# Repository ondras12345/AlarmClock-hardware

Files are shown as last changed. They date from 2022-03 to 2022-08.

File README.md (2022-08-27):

# AlarmClock Hardware
This repository contains hardware design files for [AlarmClock][AlarmClock].

Schematics and PCBs are designed in [KiCAD][KiCAD].

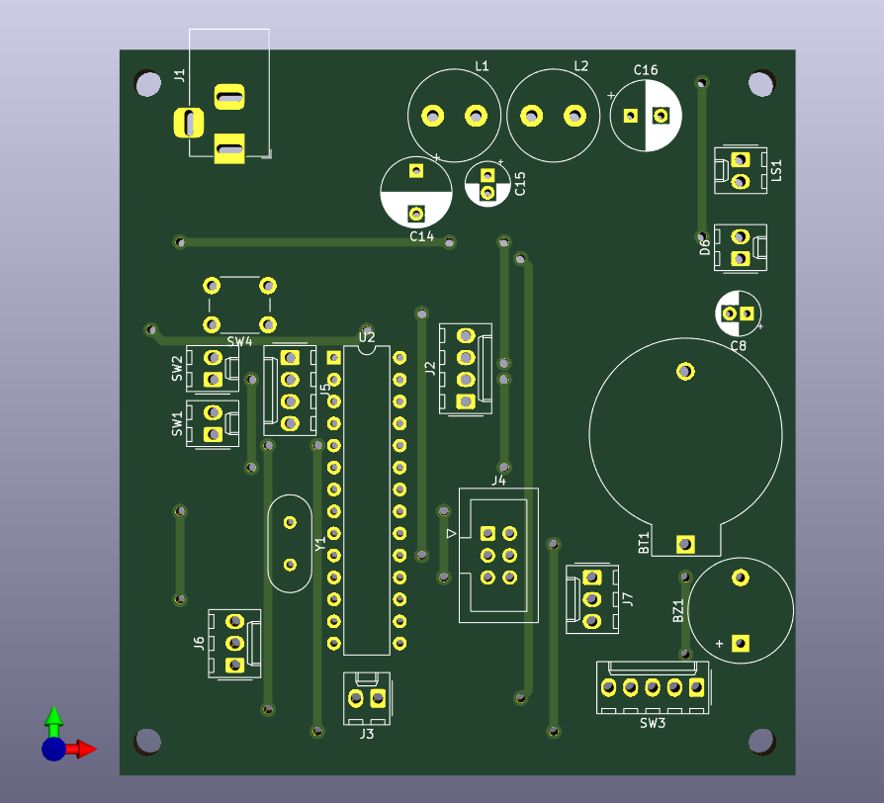
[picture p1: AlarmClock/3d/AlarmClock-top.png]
3D rendering of the top side of the PCB

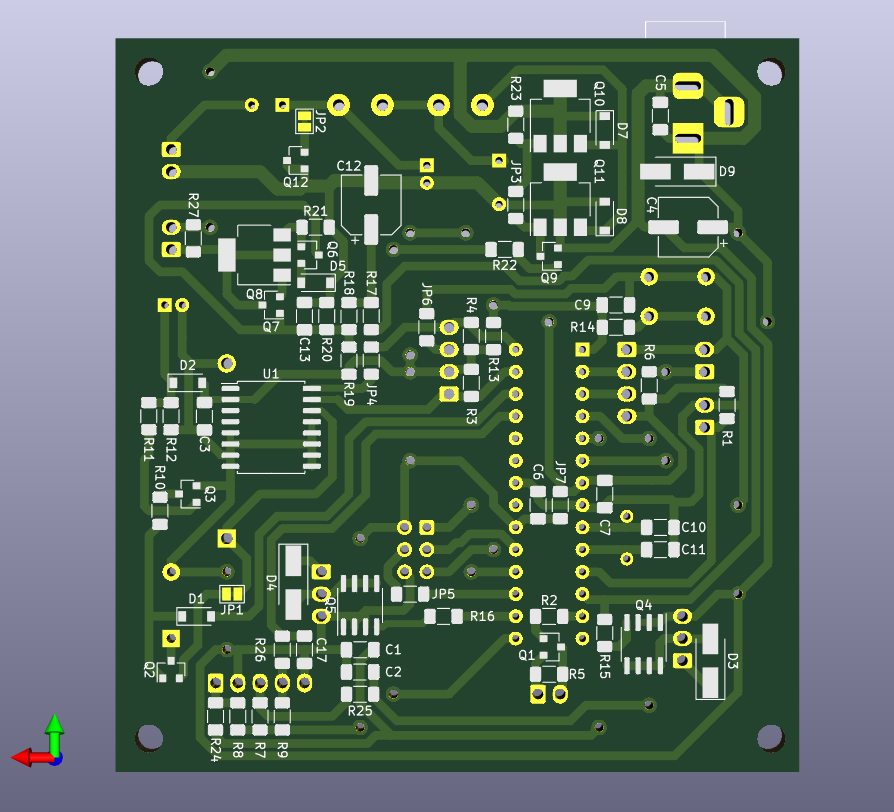
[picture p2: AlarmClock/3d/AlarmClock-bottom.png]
3D rendering of the bottom side of the PCB

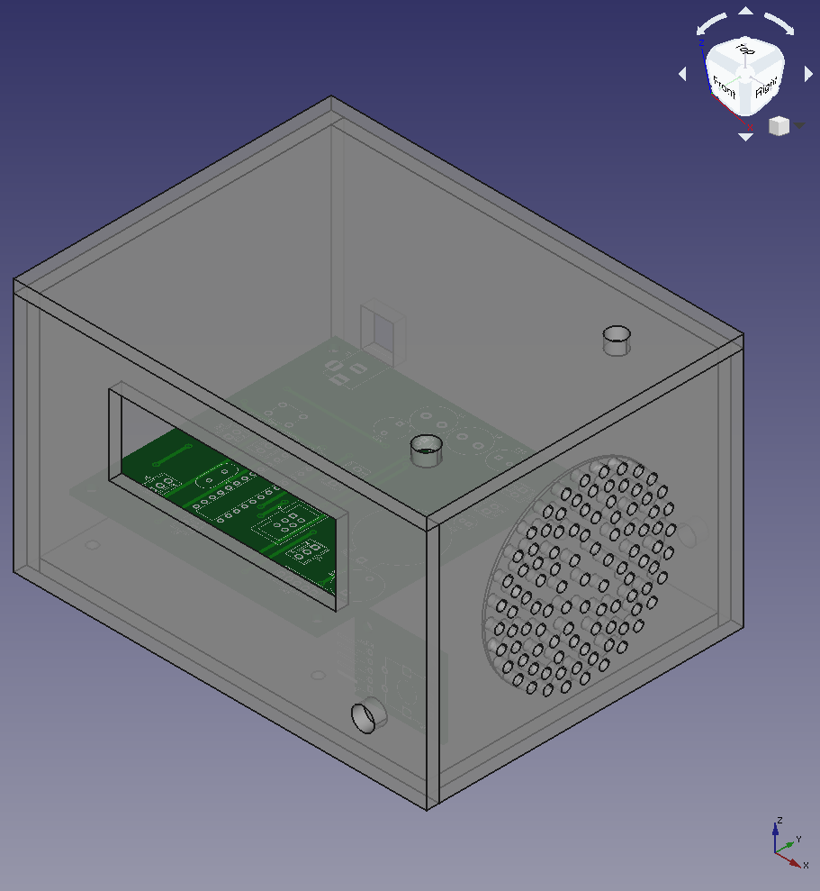
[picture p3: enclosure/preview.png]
3D view of the enclosure


[AlarmClock]: https://github.com/ondras12345/AlarmClock
[KiCAD]: https://www.kicad.org/

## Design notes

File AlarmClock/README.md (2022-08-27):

# AlarmClock
This is the main project for the whole thing. Both schematics and PCB design.

3D rendering of the top side of the PCB
3D rendering of the bottom side of the PCB

[Schematics](./AlarmClock.pdf)
[PCB](./AlarmClock-PCB.pdf)

The PCB is designed to be milled out from a single sided copper clad laminate
on a CNC machine. However, the design should also be suitable for standard
etching.

**Warning**: R27 is currently NOT included in the gcode files in `cnc/`.
However, it is quite easy to bodge in if you don't want to mess with `FlatCAM`
to fix this. Gerber files are OK.

## MCU pinout
Pin numbers in the firmware are using the convention set by the Arduino
framework. To map them to MCU pins, use the following table:

|Arduino pin | MCU pin |
|:---|:---|
| 0 | PD0 |
| 1 | PD1 |
| 2 | PD2 |
| 3 | PD3 |
| 4 | PD4 |
| 5 | PD5 |
| 6 | PD6 |
| 7 | PD7 |
| 8 | PB0 |
| 9 | PB1 |
| 10 | PB2 |
| 11 | PB3 |
| 12 | PB4 |
| 13 | PB5 |
| A0 | PC0 |
| A1 | PC1 |
| A2 | PC2 |
| A3 | PC3 |
| A4 | PC4 |
| A5 | PC5 |

- https://www.arduino.cc/en/uploads/Main/Arduino_Uno_Rev3-schematic.pdf

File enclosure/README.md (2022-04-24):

# Enclosure
This directory contains FreeCAD designs of the enclosure and gcode for
manufacturing some parts of it on a CNC mill.

The enclosure is made of 4 mm thick plywood. The sides are glued together.
The back side is removable.

3D view of the enclosure

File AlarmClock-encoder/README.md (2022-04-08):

# AlarmClock-encoder
This is just a small PCB for a Bourns PEC11R-4220K-S0024 rotary encoder.
It's only function is to connect the encoder, which is mounted to the front
panel, to a cable.

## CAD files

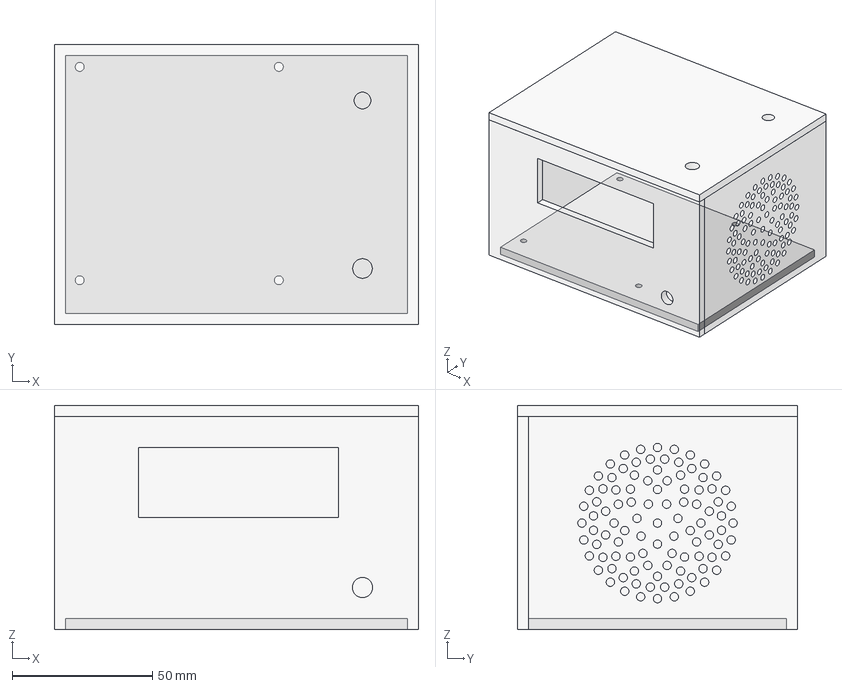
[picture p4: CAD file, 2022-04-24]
enclosure/enclosure.FCStd
130.0 x 100.0 x 80.0 mm
top
front
right
back
bottom
left

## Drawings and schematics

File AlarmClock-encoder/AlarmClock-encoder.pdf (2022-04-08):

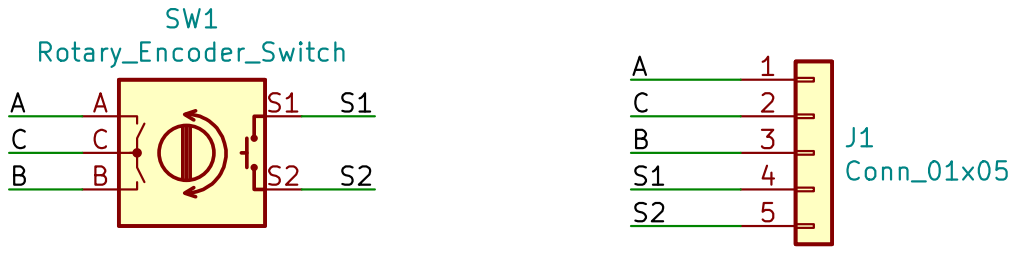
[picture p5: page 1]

Id: 1/1 Title: File: AlarmClock-encoder.sch Sheet: / Ondej Sluka

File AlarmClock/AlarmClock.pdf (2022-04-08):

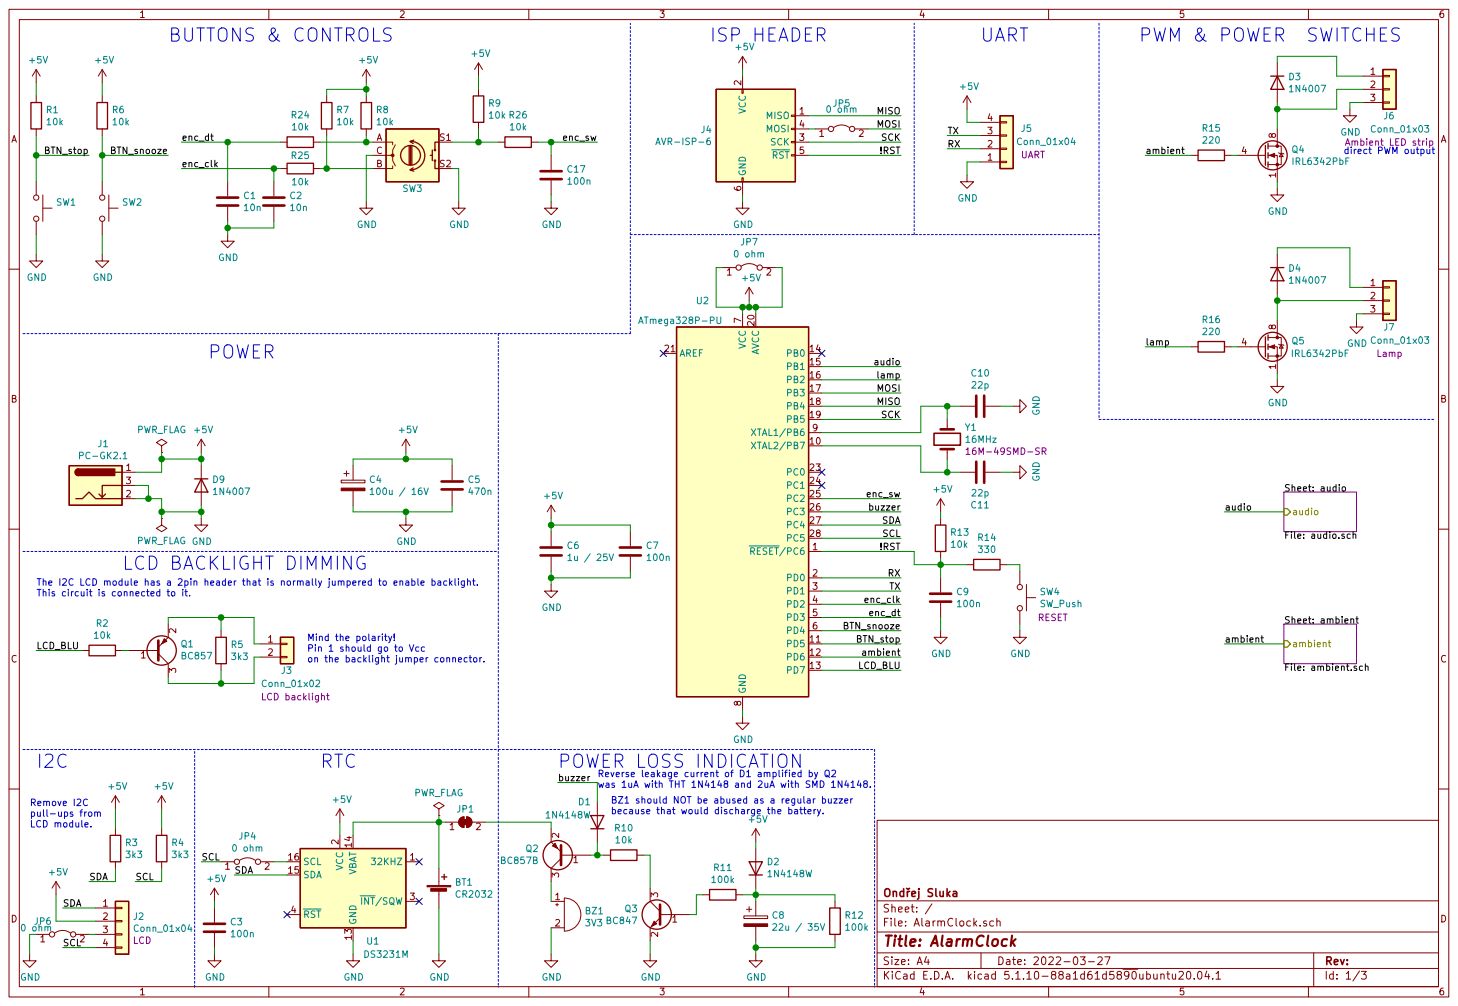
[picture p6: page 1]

2 SCK 3 MOSI 4 RST 5 GND

J6 Conn_01x03 Ambient LED strip GND

lamp
!RST SCK MOSI MISO

ambient Sheet: audio File: audio.sch

Reverse leakage current of D1 amplified by Q2 was 1uA with THT 1N4148 and 2uA with SMD 1N4148. Mind the polarity!
Pin 1 should go to Vcc
on the backlight jumper connector.

BZ1 should NOT be abused as a regular buzzer
because that would discharge the battery.

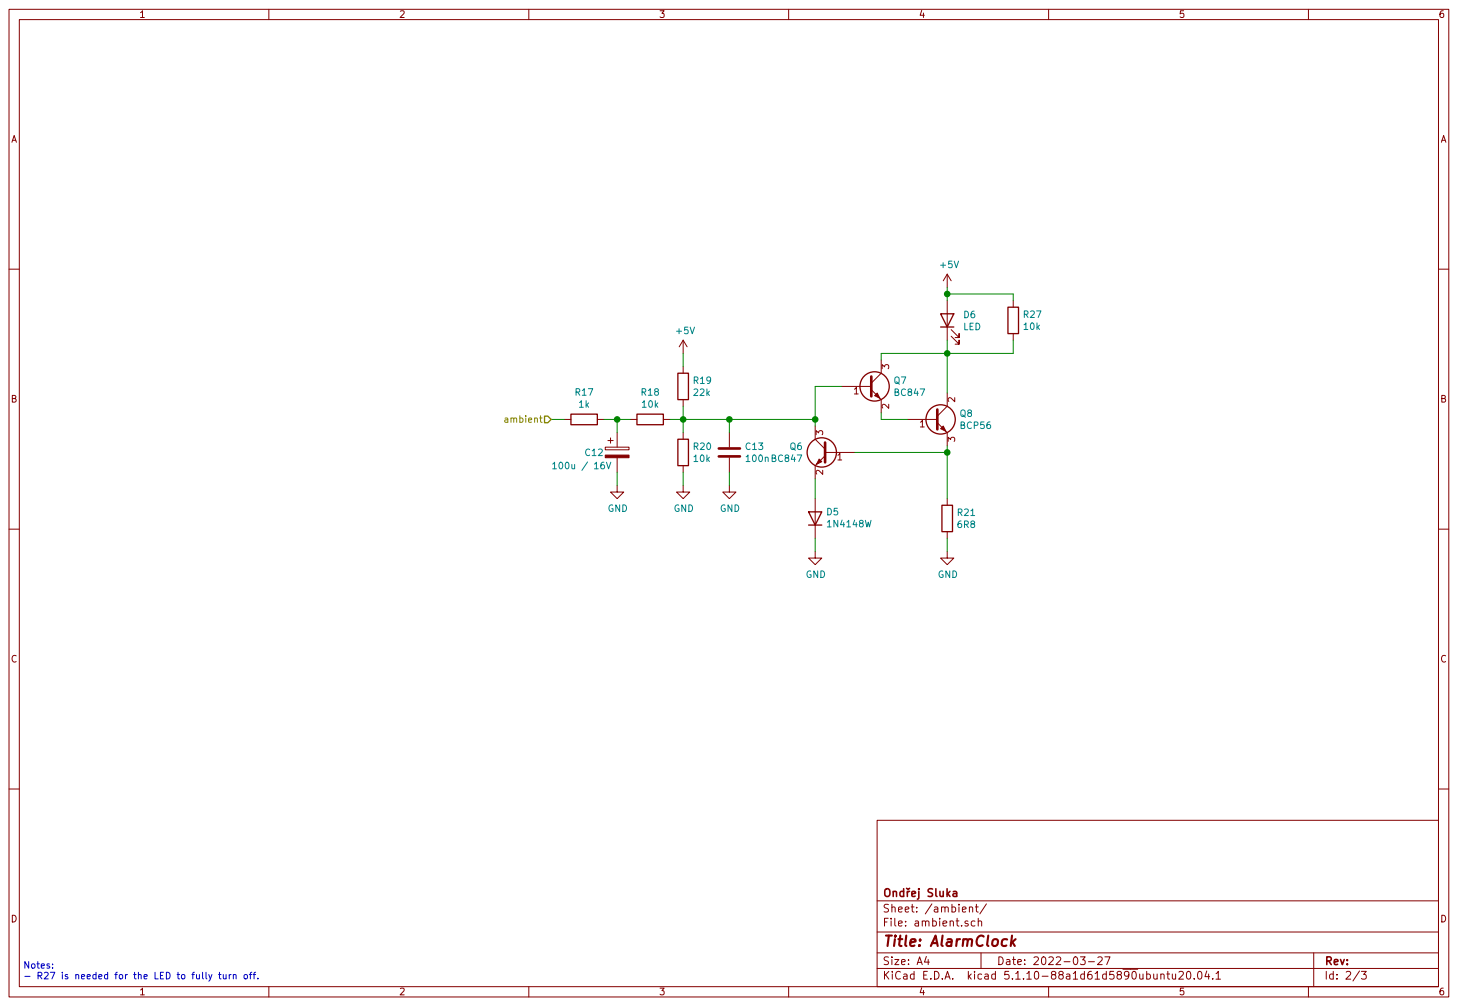
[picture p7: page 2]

2 3 Q8BCP56 ambient Notes: - R27 is needed for the LED to fully turn off.

File: ambient.sch Sheet: /ambient/ Ondej Sluka

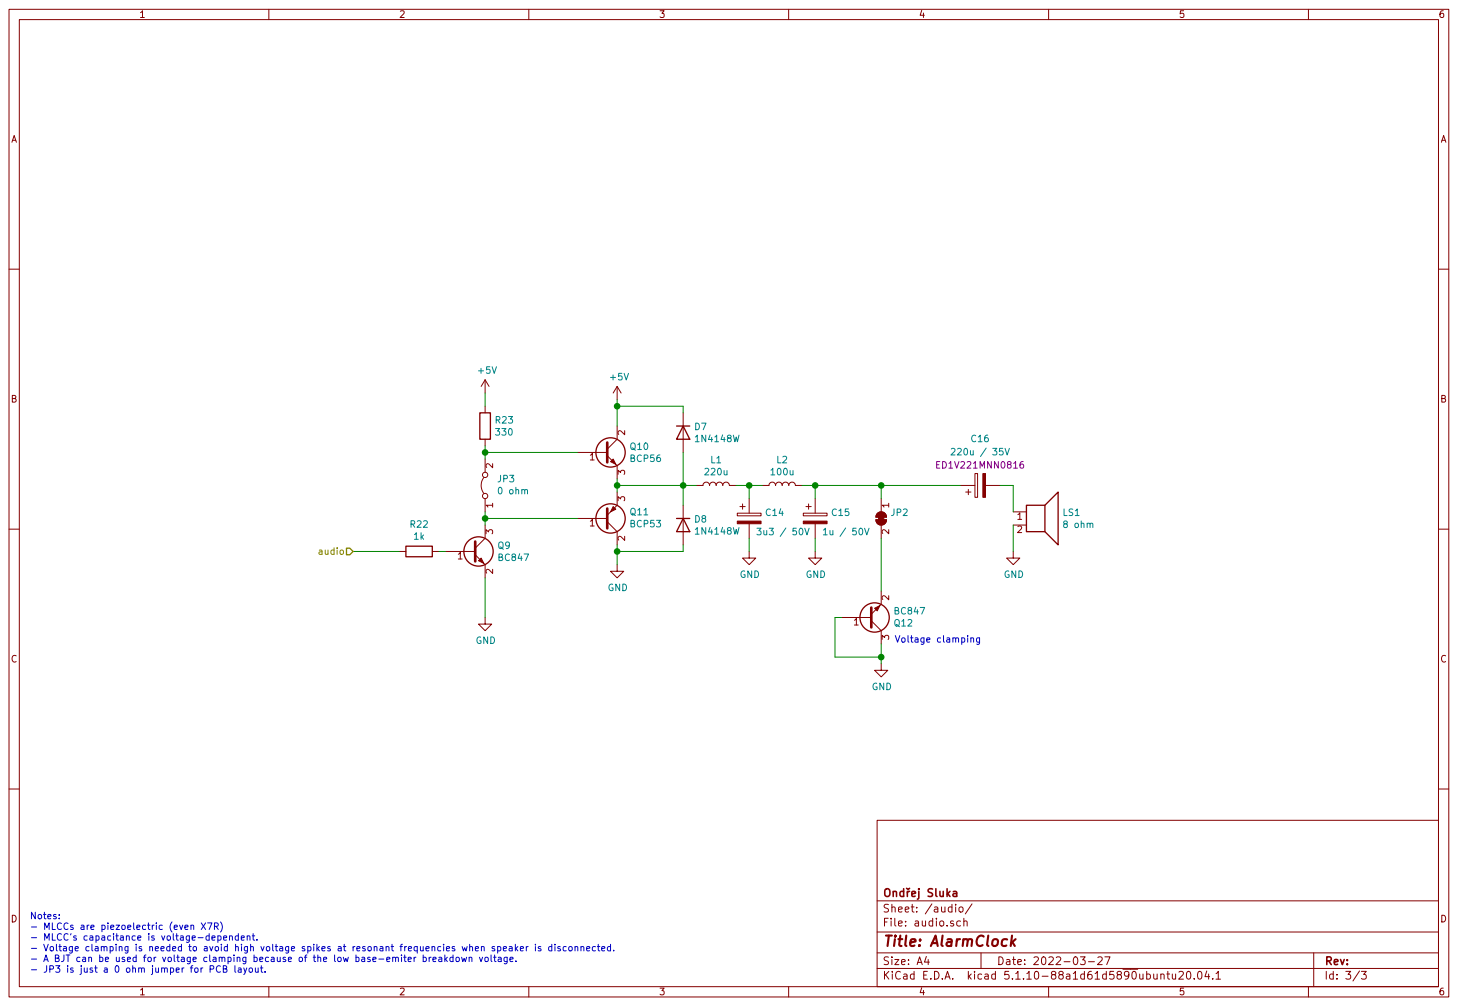
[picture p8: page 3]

audio Notes: - MLCCs are piezoelectric (even X7R)

File: audio.sch Sheet: /audio/ Ondej Sluka

- MLCC's capacitance is voltage-dependent.
- Voltage clamping is needed to avoid high voltage spikes at resonant frequencies when speaker is disconnected.
- A BJT can be used for voltage clamping because of the low base-emiter breakdown voltage.
- JP3 is just a 0 ohm jumper for PCB layout.

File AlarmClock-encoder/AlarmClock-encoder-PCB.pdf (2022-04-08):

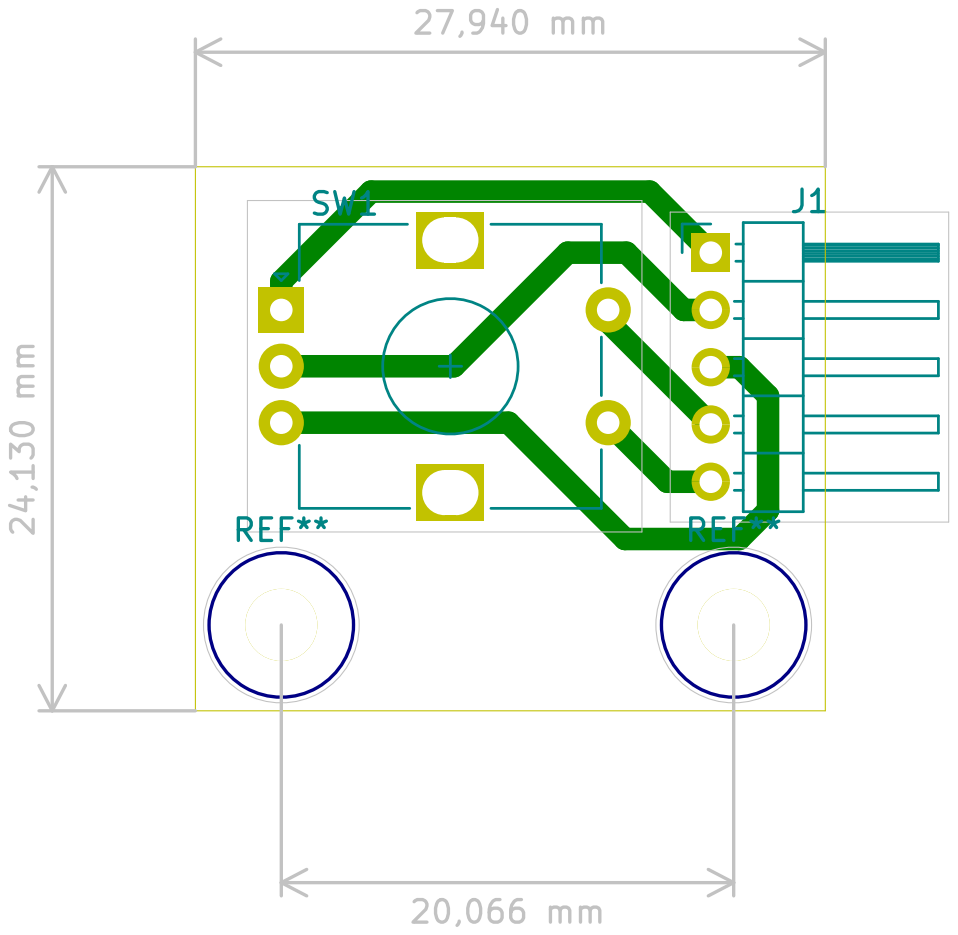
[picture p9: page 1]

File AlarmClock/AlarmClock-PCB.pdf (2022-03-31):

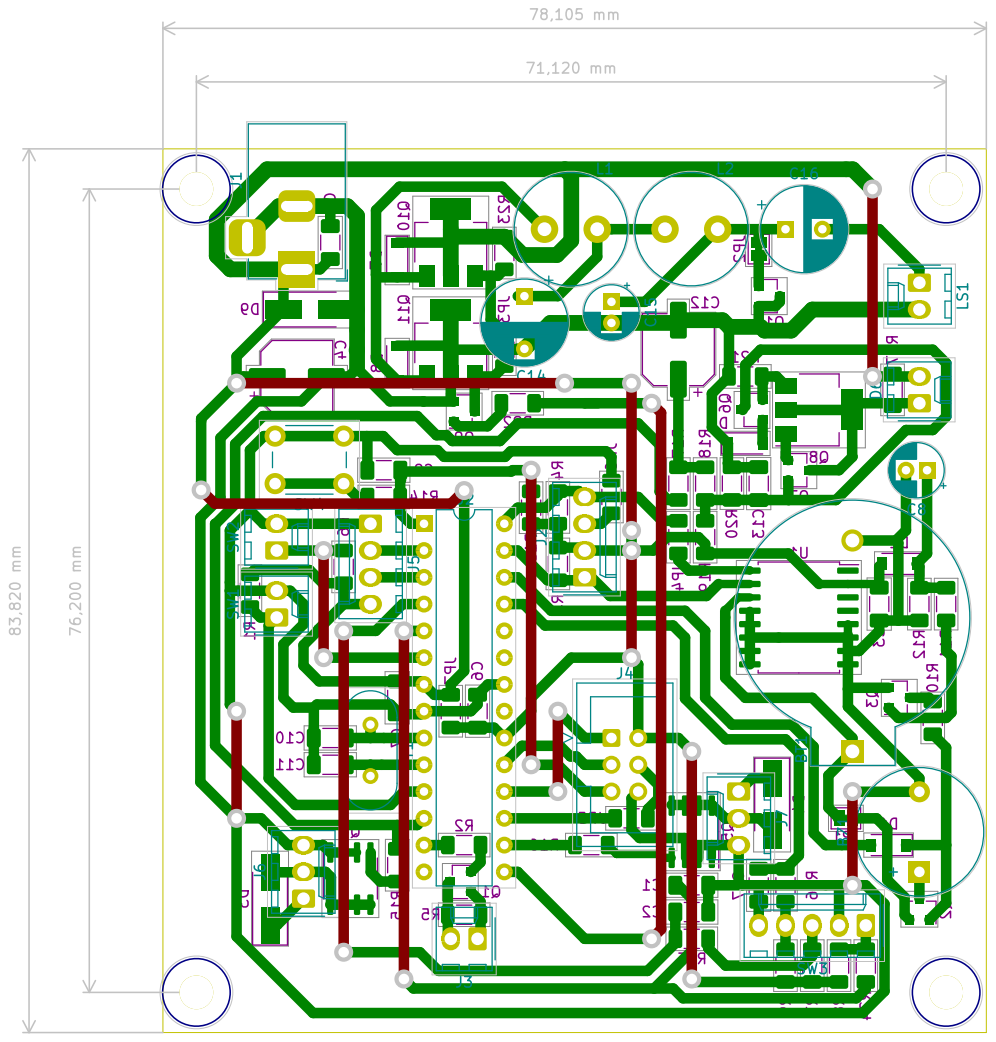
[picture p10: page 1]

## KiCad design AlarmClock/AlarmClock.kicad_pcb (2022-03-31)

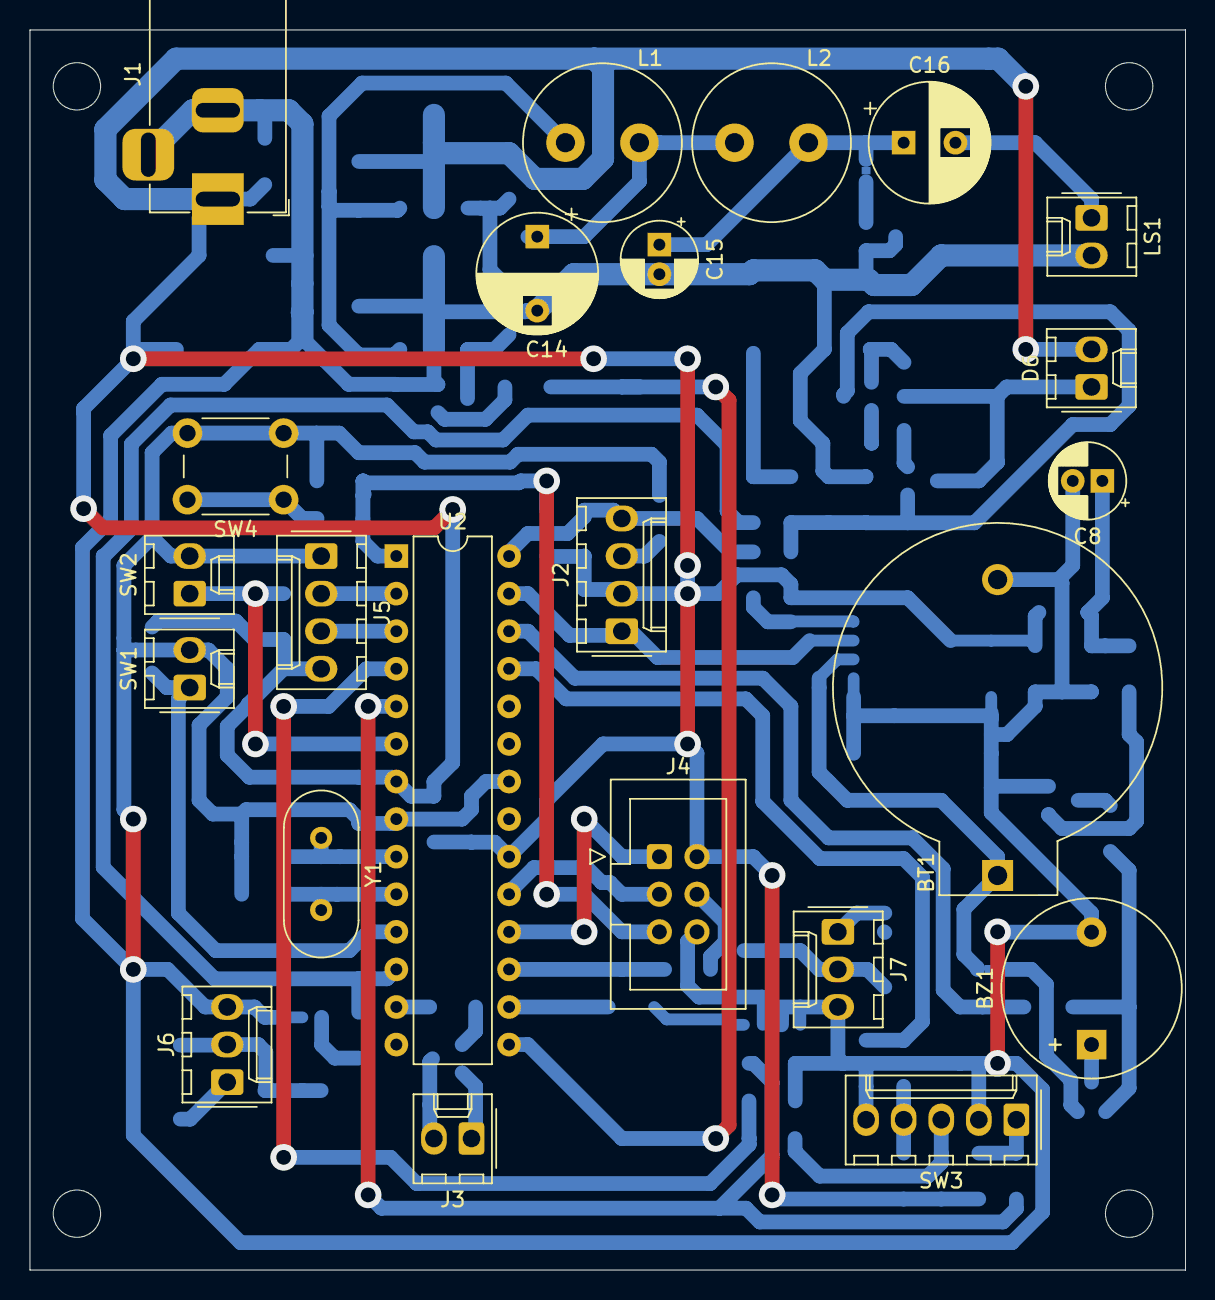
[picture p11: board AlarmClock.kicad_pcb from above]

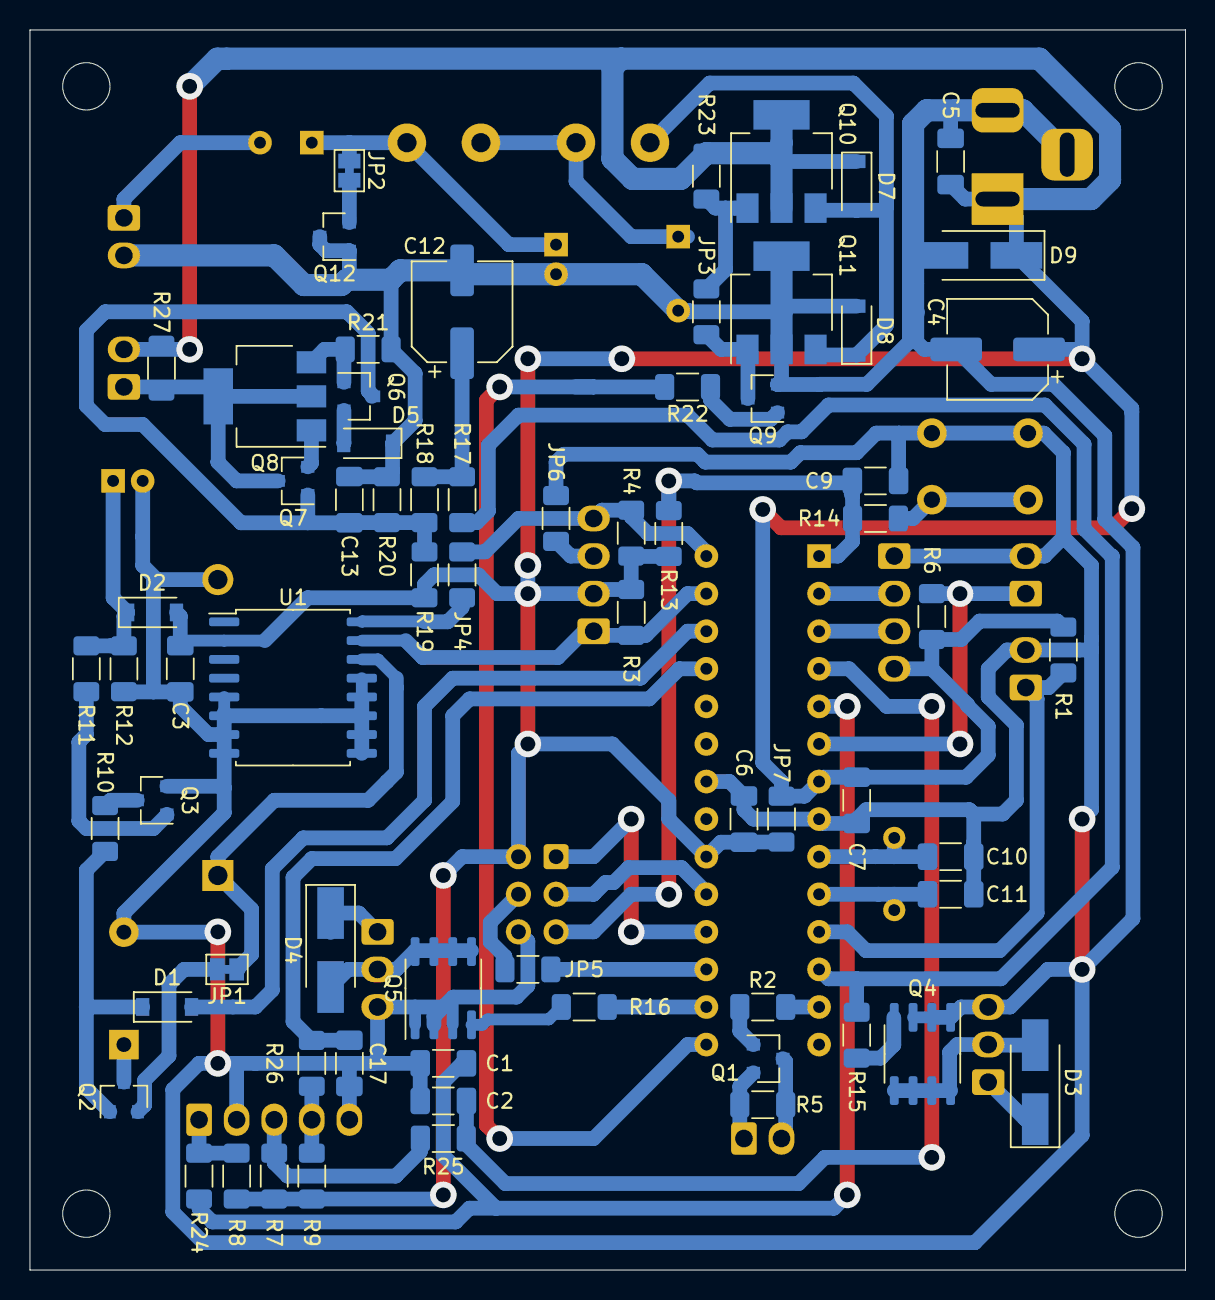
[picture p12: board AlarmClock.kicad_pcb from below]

Board: 2 copper layers, 78.1 x 83.8 mm, 91 parts (68 on the bottom side), 59 nets.

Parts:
BT1: CR2032; BatteryHolder_DS1092-04-B6P
BZ1: 3V3; Buzzer_12x9.5RM7.6
C1, C2: 10n; C_1206_3216Metric_Pad1.33x1.80mm_HandSolder
C3, C7, C9, C13, C17: 100n; C_1206_3216Metric_Pad1.33x1.80mm_HandSolder
C4, C12: 100u / 16V; CP_Elec_6.3x5.4
C5: 470n; C_1206_3216Metric_Pad1.33x1.80mm_HandSolder
C6: 1u / 25V; C_1206_3216Metric_Pad1.33x1.80mm_HandSolder
C8: 22u / 35V; CP_Radial_D5.0mm_P2.00mm
C10, C11: 22p; C_1206_3216Metric_Pad1.33x1.80mm_HandSolder
C14: 3u3 / 50V; CP_Radial_D8.0mm_P5.00mm
C15: 1u / 50V; CP_Radial_D5.0mm_P2.00mm
C16: 220u / 35V; CP_Radial_D8.0mm_P3.50mm
D1, D2, D5, D7, D8: 1N4148W; D_SOD-123
D3, D4, D9: 1N4007; D_SMA_Handsoldering
D6: LED; Molex_KK-254_AE-6410-02A_1x02_P2.54mm_Vertical
J1: PC-GK2.1; BarrelJack_Horizontal
J2, J5: Conn_01x04; Molex_KK-254_AE-6410-04A_1x04_P2.54mm_Vertical
J3: Conn_01x02; Molex_KK-254_AE-6410-02A_1x02_P2.54mm_Vertical
J4: AVR-ISP-6; IDC-Header_2x03_P2.54mm_Vertical
J6, J7: Conn_01x03; Molex_KK-254_AE-6410-03A_1x03_P2.54mm_Vertical
JP1, JP2: SolderJumper_2_Bridged; SolderJumper-2_P1.3mm_Bridged_Pad1.0x1.5mm
JP3, JP4, JP5, JP6, JP7: 0 ohm; R_1206_3216Metric_Pad1.30x1.75mm_HandSolder
L1: 220u; L_Radial_D10.5mm_P5.00mm_Abacron_AISR-01
L2: 100u; L_Radial_D10.5mm_P5.00mm_Abacron_AISR-01
LS1: 8 ohm; Molex_KK-254_AE-6410-02A_1x02_P2.54mm_Vertical
Q1: BC857; SOT-23
Q2: BC857B; SOT-23
Q3, Q6, Q7, Q9, Q12: BC847; SOT-23
Q4, Q5: IRL6342PbF; SOIC-8_3.9x4.9mm_P1.27mm
Q8, Q10: BCP56; SOT-223-3_TabPin2
Q11: BCP53; SOT-223-3_TabPin2
R1, R2, R6, R7, R8, R9, R10, R13, R18, R20, R24, R25, R26, R27: 10k; R_1206_3216Metric_Pad1.30x1.75mm_HandSolder
R3, R4, R5: 3k3; R_1206_3216Metric_Pad1.30x1.75mm_HandSolder
R11, R12: 100k; R_1206_3216Metric_Pad1.30x1.75mm_HandSolder
R14, R23: 330; R_1206_3216Metric_Pad1.30x1.75mm_HandSolder
R15, R16: 220; R_1206_3216Metric_Pad1.30x1.75mm_HandSolder
R17, R22: 1k; R_1206_3216Metric_Pad1.30x1.75mm_HandSolder
R19: 22k; R_1206_3216Metric_Pad1.30x1.75mm_HandSolder
R21: 6R8; R_1206_3216Metric_Pad1.30x1.75mm_HandSolder
SW1, SW2: SW_Push; Molex_KK-254_AE-6410-02A_1x02_P2.54mm_Vertical
SW3: Rotary_Encoder_Switch; Rotary_Encode_Switch_Molex_KK-254_AE-6410-05A_1x05_P2.54mm_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
SW4: SW_Push; SW_PUSH_6mm_H4.3mm
U1: DS3231M; SOIC-16W_7.5x10.3mm_P1.27mm
U2: ATmega328P-PU; DIP-28_W7.62mm
Y1: 16MHz; Crystal_HC49-U_Vertical

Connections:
+5V: C3.1, C4.1, C5.1, C6.1, C7.1, D2.2, D6.2, D7.1, D9.1, J1.1, J2.2, J4.2, J5.4, JP7.1, JP7.2, Q10.2, R1.1, R3.1, R4.1, R6.1, R7.1, R8.1, R9.1, R13.1, R19.1, R23.1, R27.1, U1.2, U2.7, U2.20
/!RST: C9.1, J4.5, R13.2, R14.2, U2.1
/BTN_snooze: R6.2, SW2.1, U2.6
/BTN_stop: R1.2, SW1.1, U2.11
/LCD_BLU: R2.2, U2.13
/MISO: J4.1, U2.18
/MOSI: JP5.2, U2.17
/RX: J5.2, U2.2
/SCK: J4.3, U2.19
/SCL: J2.4, JP4.1, R4.2, U2.28
/SDA: J2.1, R3.2, U1.15, U2.27
/TX: J5.3, U2.3
/ambient: R15.2, R17.2, U2.12
/audio: R22.2, U2.15
/buzzer: D1.2, U2.26
/enc_clk: C2.1, R25.2, U2.4
/enc_dt: C1.1, R24.2, U2.5
/enc_sw: C17.1, R26.1, U2.25
/lamp: R16.2, U2.16
GND: BT1.2, BZ1.2, C1.2, C2.2, C3.2, C4.2, C5.2, C6.2, C7.2, C8.2, C9.2, C10.1, C11.2, C12.2, C13.2, C14.2, C15.2, C17.2, D5.1, D8.2, D9.2, J1.2, J1.3, J4.6, J5.1, J6.3, J7.3, JP6.1, LS1.2, Q3.2, Q4.1, Q4.2, Q4.3, Q5.1, Q5.2, Q5.3, Q9.2, Q11.2, Q12.1, Q12.3, R12.2, R20.2, R21.2, SW1.2, SW2.2, SW3.C, SW3.S2, SW4.2, U1.5, U1.6, U1.7, U1.8, U1.9, U1.10, U1.11, U1.12, U1.13, U2.8, U2.22
unnamed: BT1.1, JP1.1, U1.14
unnamed: BZ1.1, Q2.3
unnamed: C8.1, D2.1, R11.1, R12.1
unnamed: C10.2, U2.9, Y1.1
unnamed: C11.1, U2.10, Y1.2
unnamed: C12.1, R17.1, R18.2
unnamed: C13.1, Q6.3, Q7.1, R18.1, R19.2, R20.1
unnamed: C14.1, L1.2, L2.1
unnamed: C15.1, C16.1, JP2.1, L2.2
unnamed: C16.2, LS1.1
unnamed: D1.1, Q2.1, R10.2
unnamed: D3.1, J6.1
unnamed: D3.2, J6.2, Q4.5, Q4.6, Q4.7, Q4.8
unnamed: D4.1, J7.1
unnamed: D4.2, J7.2, Q5.5, Q5.6, Q5.7, Q5.8
unnamed: D5.2, Q6.2
unnamed: D6.1, Q7.3, Q8.2, R27.2
unnamed: D7.2, D8.1, L1.1, Q10.3, Q11.3
unnamed: J2.3, JP6.2
unnamed: J3.1, Q1.2, R5.1
unnamed: J3.2, Q1.3, R5.2
unnamed: J4.4, JP5.1
unnamed: JP1.2, Q2.2
unnamed: JP2.2, Q12.2
unnamed: JP3.1, Q9.3, Q11.1
unnamed: JP3.2, Q10.1, R23.2
unnamed: JP4.2, U1.16
unnamed: Q1.1, R2.1
unnamed: Q3.1, R11.2
unnamed: Q3.3, R10.1
unnamed: Q4.4, R15.1
unnamed: Q5.4, R16.1
unnamed: Q6.1, Q8.3, R21.1
unnamed: Q7.2, Q8.1
unnamed: Q9.1, R22.1
unnamed: R14.1, SW4.1
unnamed: R8.2, R24.1, SW3.A
unnamed: R7.2, R25.1, SW3.B
unnamed: R9.2, R26.2, SW3.S1

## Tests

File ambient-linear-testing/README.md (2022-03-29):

# ambient-linear-testing
This project contains the schematics of a circuit that was used during testing
to dim a 1W LED. It is not used in the final product.

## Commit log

2022-03-29 Add project files
    [ambient-linear-testing.kicad_pcb, ambient-linear-testing.sch]
2022-03-29 Add main project schematic
    [AlarmClock.kicad_pcb, AlarmClock.sch, ambient.sch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]
2022-03-29 Annotate schematics, assign footprints, pcbnew
    [AlarmClock.kicad_pcb, AlarmClock.sch, ambient.sch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]
2022-03-29 Design the PCB
    [AlarmClock.kicad_pcb, AlarmClock.sch, ambient.sch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]
2022-03-29 Add data for PCB manufacture
2022-03-29 Populate I2C pull-up resistors
    [AlarmClock.kicad_pcb, AlarmClock.sch]
2022-03-31 Fix ambient LED staying lit
    [AlarmClock.kicad_pcb, AlarmClock.sch, ambient.sch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]
2022-04-08 Update text in AlarmClock schematic
    [AlarmClock.sch]
2022-04-08 Add AlarmClock-encoder
    [AlarmClock-encoder.kicad_pcb, AlarmClock-encoder.sch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]
2022-04-13 Update symbol fields for BOM
    [AlarmClock.sch, ambient.sch, audio.sch]
2022-04-24 Add FreeCAD designs of the enclosure
    [enclosure.FCStd]
